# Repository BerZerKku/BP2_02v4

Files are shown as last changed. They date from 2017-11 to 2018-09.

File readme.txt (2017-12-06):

BP2
Блок питания задний для аппаратуры АВАНТ.

Версия платы: 02v7.
Дата создания: декабрь 2017.
Среда разработки: OrCAD 16.6-S073.
База: greysql.

Код ПП: 3.140.626
Код ПП в сборе: 2.140.896

Изменения:
Добавлен PFC и входной фильтр (за основу взяты платы AVAX_PWR_PFCS6_V100 и AVAX_PWR_PFCS6_V110). 
Источники AC-DC оставлены только TMG.
Изменены держатели для предохранителей.
Изменена схема компаратора в управлении 24В -> 5В.

Пороги для управления 5В рассчетные / реальные:
***Включение - 22 В / ?? В.
***Выключение - 20 В / ?? В. 

Пороги для управления 220В рассчетные / реальные:
***Включение - ?? В / ?? В.
***Выключение -?? В / ?? В.

Стэк:
0.035 TOP
1.500  
0.035 BOTTOM

Габариты платы: 233мм х 103мм
Материал: FR4 (e=4.1, plating thickness=25um))
Финишное покрытие контактных площадок: HAL
Паяльная маска: зеленая.
Маркировка: только со стороны TOP.
Вырезы на плате: есть.
Отверстия указаны после металлизации.

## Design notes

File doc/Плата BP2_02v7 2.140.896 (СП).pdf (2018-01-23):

Напечатано: 19 января 2018 г. 14:16:34, Щеблыкин Михаил Владимирович
Поз. | Наименование | Корпус | Кол. | Поз. по Э3 | Примечание
| Документация
| Сборочный чертеж 2.140.896 | | 0
| Сборочные единицы
1 | [3.181.006] Радиатор для AVAX.PWR.PFCS6 | LEAD-2 | 1 | B1
| Детали
2 | [3.140.626] Печатная плата BP2_02v7 2L/200um/0.4mm | | 1
| Прочее
| Источники питания
3 | [TMG 15105] Преобразователь напряжения TMG 15105 TRACO | DIP4 | 1 | UG1
4 | [TMG 15124] Преобразователь напряжения TMG 15124 TRACO | DIP4 | 1 | UG2
| Конденсаторы
7 | [B41858C6477M] Конденсатор B41858C6477M 470uF 50V 20% Epcos | LEAD | 2 | C1, C6
8 | [1210-X5R-50V-10uF -10%] Чип-конденсатор 1210 X5R 50V 10uF 10% | 1210 | 2 | C2, C7
9 | [DE1B3KX471KA5B] Конденсатор DE1B3KX471KA5B 470pF 250V 10% X1/Y1 Murata | LEAD | 2 | C3, C4 | Допустимые замены: [DE1B3KX471KA4 BN01F] Конденсатор DE1B3KX471KA4B N01F Murata

2.140.896

| Лист | № докум | Подп. | Дата
Разраб. | Щеблыкин М.В. | | 01.12.2017 | Плата BP2_02v7 (Плата BP2_02v7) | Лит. | Лист | Листов
Провер. | Вершинин А.С. | | 01.12.2017 | | | 1 | 9
Т.контр. | Бокова Т.И. | | 01.12.2017 | | Прософт-Системы
Н.контр. | Назаренко А.Н. | | 01.12.2017
Утв. | Чирков А.Г. | | 01.12.2017

10 | [B43501B9107M] Конденсатор B43501B9107M Epcos | LEAD | 1 | C5
11 | [B32922C3474M] Конденсатор B32922C3474M 305V | LEAD | 3 | C10, C11, C20
| 0.47uF 20% Epcos
12 | [DECE33J222ZC4B] Конденсатор DECE33J222ZC4B 2200pF 6.3kV Murata | LEAD | 4 | C12-C15
13 | [2220-X7R-1000V-0. 1uF-10%] Чип-конденсатор 2220 X7R 1000V 0.1uF 10% | 2220 | 2 | C16, C23
14 | [UBT1E101MPD1TD] Конденсатор UBT1E101MPD1TD 25V 100uF 20% 8*13.5mm Nichicon | LEAD | 1 | C17
15 | [0603-X7R-50V-0.1u F-10%] [+] Чип-конденсатор 0603 X7R 50V 0.1uF 10% | 0603 | 4 | C18, C29, C31, C33
16 | [1210-X7R-25V-10uF -10%] [+] Чип-конденсатор 1210 X7R 25V 10uF 10% | 1210 | 1 | C19
17 | [EEU-ED2G470S] Конденсатор EEU-ED2G470S 47UF 400V 20% Panasonic | LEAD | 2 | C21, C22
18 | [0603-NP0-50V-820p F-5%] Чип-конденсатор 0603 NP0 50V 820pF 5% | 0603 | 1 | C24

2.140.896

Лист

2 Изм | Лист | № докум | Подп. | Дата

19 | [0603-X7R-50V-1500 pF-10%] Чип-конденсатор 0603 X7R 50V 1500pF 10% | 0603 | 1 | C25
20 | [0603-X5R-10V-10uF -10%] Чип-конденсатор 0603 X5R 10V 10uF 10% | 0603 | 2 | C26, C32
21 | [0603-X7R-50V-0.15 uF-10%] Чип-конденсатор 0603 X7R 50V 0.15uF 10% | 0603 | 1 | C27
22 | [0603-NP0-50V-680p F-5%] Чип-конденсатор 0603 NP0 50V 680pF 5% | 0603 | 1 | C28
23 | [0603-X7R-50V-1uF-10%] Чип-конденсатор 0603 X7R 50V 1uF 10% | 0603 | 1 | C30
24 | [0603-X7R-50V-0.01 uF-10%] [+] Чип-конденсатор 0603 X7R 50V 0.01uF 10% | 0603 | 2 | C34, C35
| Предохранители,держатели предохранителей
30 | [ZH214-040] Предохранитель 4А 5*20мм Zhenhui Electronics | | 2 | F1, F2
| Дроссели, фильтры, катушки индуктивности
34 | [SDR2207-4R7ML] Индуктивность SDR2207-4R7ML Bourns | SMT-2 | 2 | L1, L2
35 | [744834407] Дроссель 744834407 Wurth | LEAD-4 | 2 | L3, L4
| | | | 3 Изм
Лист | № докум | Подп. | Дата

36 | [CDRH127/LDNP-471M C] Индуктивность CDRH127/LDNP-471MC | SMD | 1 | L5
| Sumida
37 | [2.210.500] Дроссель AVAX.PWR.PFCINDUCT OR-v1.0.0 (AVAX.PWR.PFCINDUC TOR-v1.0.0 СП) | SMD | 1 | L6
| Резисторы
41 | [1210-33K-5%] Чип-резистор 1210 33K 5% | 1210 | 4 | R1, R3-R5
42 | [1206-1K-5%] Чип-резистор 1206 1K 5% | 1206 | 1 | R2
43 | [1206-4.7K-5%] Чип-резистор 1206 4.7K 5% | 1206 | 1 | R6
44 | [1206-1-1%] Чип-резистор 1206 1 1% | 1206 | 1 | R7
45 | [1206-200K-5%] Чип-резистор 1206 200K 5% | 1206 | 3 | R8, R10, R11
46 | [0603-10K-5%] Чип-резистор 0603 10K 5% | 0603 | 7 | R9, R16, R24, R31, R32, R34, R36
47 | [1206-150K-1%] Чип-резистор 1206 150K 1% | 1206 | 1 | R12
48 | [0805-51K-1%] Чип-резистор 0805 51K 1% | 0805 | 1 | R13
49 | [2512-0.051-5%] Чип-резистор 2512 0.051 5% | 2512 | 1 | R14
50 | [1206-510K-1%] Чип-резистор 1206 510K 1% | 1206 | 2 | R15, R19
| | | | 4 Изм
Лист | № докум | Подп. | Дата

51 | [0603-3.3-5%] Чип-резистор 0603 3.3 5% | 0603 | 1 | R17
52 | [0603-220-5%] Чип-резистор 0603 220 5% | 0603 | 1 | R18
53 | [0603-51K-1%] Чип-резистор 0603 51K 1% | 0603 | 1 | R20
54 | [0603-18K-1%] Чип-резистор 0603 18K 1% | 0603 | 1 | R21
55 | [0603-14.7K-1%] Чип-резистор 0603 14.7K 1% | 0603 | 1 | R22
56 | [0603-2K-1%] Чип-резистор 0603 2K 1% | 0603 | 1 | R23
57 | [0603-1M-1%] Чип-резистор 0603 1M 1% | 0603 | 1 | R25
58 | [0603-4.7K-5%] Чип-резистор 0603 4.7K 5% | 0603 | 1 | R26
59 | [0805-100K-1%] [+] Чип-резистор 0805 100K 1% | 0805 | 3 | R27-R29
60 | [0603-10K-1%] Чип-резистор 0603 10K 1% | 0603 | 1 | R30
61 | [0603-2.2K-5%] Чип-резистор 0603 2.2K 5% | 0603 | 2 | R33, R37
62 | [0603-10.5K-1%] Чип-резистор 0603 10.5K 1% | 0603 | 1 | R35
63 | [0603-8.25K-1%] Чип-резистор 0603 8.25K 1% | 0603 | 1 | R38
64 | [0603-255K-1%] Чип-резистор 0603 255K 1% | 0603 | 1 | R39
| | | | 5 Изм
Лист | № докум | Подп. | Дата

65 | [0603-2.4K-1%] Чип-резистор 0603 2.4K 1% | 0603 | 1 | R40
66 | [JVR-14N391K] Варистор JVR-14N391K | LEAD-2 | 1 | RV1
67 | [JNR15S470L] Термистор JNR15S470L | LEAD-2 | 1 | TH1
68 | [JNR15S070L] Резистор JNR15S070L терморезистор Joyin | LEAD-2 | 1 | TH2
| Микросхемы
74 | [UCC28722DBV] Микросхема UCC28722DBV SOT23-6 TI | SOT23-6 | 1 | U1
75 | [UCC28180D] Микросхема UCC28180D SOIC8 TI | SOIC8 | 1 | U2
76 | [TL431AIDBZ] Микросхема TL431AIDBZ SOT23-3 TI | SOT23-3 | 2 | U3, U5
77 | [ACPL-M50L-500E] Микросхема ACPL-M50L-500E SO5 Avago | SO5 | 1 | U4
| Диоды,светодиоды,супрессоры,стабилитроны
81 | [S3M] Диод S3M SMC | SMC(DO -214 | 1 | D1
82 | [GBU8J-BP] Диодный мост GBU8J-BP MCC | SIP4 | 1 | D2
83 | [SM4007] Диод SM4007 DO-213AB | DO-213 AB | 1 | D3
84 | [US1M] Диод US1M /1A, 1000V, 100ns SMA/DO-214AC | SMA(DO -214 | 1 | D4
| | | | 6 Изм
Лист | № докум | Подп. | Дата

85 | [ES1J] Диод ES1J SMA | DO-214 AC | 1 | D5
86 | [BZX84C24] Стабилитрон BZX84C24 SOT23 | SOT23-3 | 1 | D6
87 | [1N5408] Диод 1N5408 DO-201AD | DO-201 AD | 1 | D7
88 | [C3D06060F] Диод C3D06060F Cree | TO220-2 | 1 | D8
89 | [MBR0540] Диод MBR0540 SOD123 | SOD123 | 1 | D9
90 | [KP-1608SGC] Светодиод KP-1608SGC Kingbright (level:3) | 0603 | 1 | D10
| Транзисторы
94 | [FJP2145TU] Транзистор FJP2145TU TO-220AB ONS | TO-220 AB | 1 | Q1
95 | [IPP60R099C7XKSA1] Транзистор IPP60R099C7XKSA1 TO-220 Infineon | TO220 | 1 | Q2
96 | [IRLML5103] Транзистор IRLML5103 SOT23 IR | SOT23-3 | 2 | Q3, Q5
97 | [IRF7410] Транзистор IRF7410 SOIC8 IR | SOIC8 | 1 | Q4
| Соединители
101 | [MC000830] Держатель предохранителя MC000830 MULTICOMP | LEAD-2 | 2 | FU1, FU2
102 | [09061152911] Соединитель DIN41612-H15MS-C2A -1 | 15 | 1 | X1
| | | | 7 Изм
Лист | № докум | Подп. | Дата

103 | [231-536/001-000] | 6 | 1 | X2
| Вилка 1X1 шаг
| 5,08 мм (100 шт)
| | | | 8 Изм
Лист | № докум | Подп. | Дата

Лист регистрации ревизий

№ ревизии | № замененных (измененных) страниц | Дата ревизии | Краткое содержание и причина внесения изменений | Примечание
0 | вновь | 01.12.17

2.140.896

9

Лист Изм. | Лист | № докум. | Подп. | Дата

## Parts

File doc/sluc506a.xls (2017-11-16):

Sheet: DESIGN INPUTS AND CALCULATIONS
UCC28180 DESIGN CALCULATOR TOOL
TI Literature Number: | SLUC506 | Rev A
UCC28180 CONTINUOUS CURRENT CONDUCTION MODE PFC CONTROLLER WITH PROGRAMMABLE SWITCHING FREQUENCY
Please enter design parameters into the | shaded | cells;
Calculated results will be in RED
Be sure to ENABLE EDITING before attempting to use this design calculator
This spreadsheet guides the user through the design process of a CONTINUOUS CONDUCTION MODE PFC BOOST CONVERTER using the UCC28180. User interaction is required in order to get the best possible results. Enter the desired specification where prompted, the highlighted cells are for user inputs; calculations for the design are based upon the inputs.
WHERE APPLICABLE, A RECOMMENDED VALUE IS GIVEN THAT WILL BE THE BEST CHOICE TO MEET THE GIVEN SPECIFICATION. IT IS IN THE BEST INTEREST OF THE USER TO USE A VALUE AS CLOSE AS POSSIBLE TO THE SUGGESTED RECOMMENDED VALUE. FOR ACCURATE RESULTS, THE USER MUST ENTER THE ACTUAL VALUE USED IN THE APPROPRIATE CELL.
Disclaimer
This product is designed as an aid for customers of Texas Instruments. No warranties, either expressed or implied, with respect to this software or its fitness for any particular purpose, are claimed by Texas Instruments or the author. The software is licensed solely on an "as is" basis. The entire risk as to its quality and performance is with the customer.
INPUT:
Minimum Input Voltage from AC Line: | VACIN(min) | 82 | VRMS
Maximum Input Voltage from AC Line: | VACIN(max) | 242 | VRMS
Minimum Line Frequency: | fLINE(min): | 47 | Hz
Maximum Line Frequency: | fLINE(max): | 63 | Hz
Minimum Rectified AC Line Voltage: | VIN_PEAK(min) | 115.966 | V
Maximum Rectified AC Line Voltage: | VIN_PEAK(max) | 342.240 | V
OUTPUT:
Maximum Output Power of PFC Stage: | POUT(max) | 190 | W
Output Voltage (Note: Must be > VIN_RECTIFIED(max)): | VOUT | 350 | V
Target Power Factor, VIN(nom), Full Load: | PF | 0.99
Predicted Efficiency: | h | 0.95
Maximum Ambient Temperature: | TAMB(max) | 50 | °C
Maximum Average Output Current of PFC Stage: | IOUT | 0.543 | A
Desired Switching Frequency: | fSW(target) | 120 | kHz
Recommended Resistor value on FREQ to Set the Switching Frequency, fSW: | RFREQ(recommended) | 17.800 | kΩ
Actual Value For RFREQ Used: | RFREQ = | 18 | kΩ
Resultant Switching Frequency, fSW: | fSW | 116.402 | kHz
Line Current:
Maximum Input Power Drawn from the Line: | PIN(max) | 200.000 | W
Maximum RMS AC Line Current: | IIN_RMS(max) | 2.464 | A
Maximum Peak AC Line Current, assuming sinusoidal: | IIN_PEAK(max) | 3.484 | A
Maximum Average AC Line Current, assuming sinusoidal: | IIN_AVG(max) | 2.218 | A
Minimum Input Fuse Rating: | IFUSE | 3.695 | A
BRIDGE RECTIFIER:
Bridge Rectifier Forward Voltage, at IIN_PEAK(max): | VF_BRIDGE | 1 | V
Bridge Rectifier Thermal Resistance, Junction to Case: | RqJC(Bridge) | 2.2 | °C/W
Case to Heatsink Thermal Resistance: | RθCHS(Bridge) | 0.61 | °C/W
Bridge Rectifier Maximum Junction Temperature: | TJ(max) | 125 | °C
Bridge Rectifier Minimum Average Current Rating: | IBRIDGE(rated) | 3.327 | A
Bridge Rectifier Minimum DC Blocking Voltage Rating: | VDC_BLOCKING(rated) | 376.464 | V
Bridge Rectifier Power Dissipation: | PBRIDGE | 4.436 | W
Required Heat Sink Thermal Impedance: | RqHS_AMB(Bridge) | 14.097 | °C/W
INPUT CAPACITOR:
Inductor Peak-to-Peak Current Ripple Factor (i.e. 0.2 for 20%, 0.3 for 30%). Percentage of minimum input, maximum load, inductor current at 50% duty cycle operating point, not recommended to be > 0.4: | LI_ripple_factor(target) | 0.4
Maximum High Frequency Voltage Ripple Factor (i.e. 0.03 for 3%, 0.09 for 9%): | VCin_ripple_factor | 0.07
Target Maximum Allowable Inductor Current Ripple: | IRIPPLE(target) | 1.394 | A
Maximum Inductor Voltage Ripple: | VIN_RIPPLE | 8.118 | V
Recommended Input Capacitor Value: | CIN(recommended) | 0.180 | mF
Actual Value of Input Capacitor Used: | CIN | 0.470 | µF
Required Minimum Voltage Rating for CIN: | VCIN(rating) | 376.464 | V
BOOST INDUCTOR DESIGN:
Maximum Duty Cycle: | DUTY(max) | 0.669
Maximum Inductor Peak Current: | IL_PEAK(max) | 4.181 | A
Minimum Recommended Boost Inductor Value: | LBST(recommended) | 0.539 | mH
Actual Boost Inductor Value Used: | LBST(actual) = | 0.6 | mH
Actual Maximum Inductor Ripple Current: | IRIPPLE(actual) | 1.253 | A
Actual Maximum Inductor Peak Current: | IL_PEAK(actual) | 4.111 | A
Resultant Inductor Current Ripple Factor: | LI_ripple_factor(actual) | 0.360
BOOST DIODE:
Forward Voltage Drop, at IL_PEAK(max),125°C: | VF | 1 | V
Reverse Recovery Charge: | QRR | 0 | nC
Boost Diode Maximum Junction Temperature: | TJ(max) | 125 | °C
Boost Diode Thermal Resistance, Junction to Case: | RqJC(Diode) | 1.5 | °C/W
Boost Diode Thermal Resistance, Case to Heatsink: | RqCHS(Diode) | 0.32 | °C/W
Boost Diode Conduction Losses: | PDIODE(cond) | 0.543 | W
Reverse Recovery Losses: | PREVERSE | 0.000 | W
Total Boost Diode Losses: | PDIODE(total) | 0.543 | W
Required Heat Sink Thermal Impedance: | RqHS_AMB(Diode) | 136.338 | °C/W
Required Diode Blocking Voltage: | VBLOCKING | 385.000 | V
SWITCHING ELEMENT:
VCC Bias Voltage to the UCC28180: | VCC | 15 | V
Gate-Source Voltage: | VGS | 13.75 | V
Drain-Source RMS Current: | IDS_RMS | 1.964 | A
FET On-Resistance at TJ = 125°C: | RDSon | 0.35 | W
FET Gate Charge at VGS: | Qg | 87 | nC
FET Rise Time: | tr | 5 | ns
FET Fall Time: | tf | 4.5 | ns
FET Output Capacitance: | COSS | 780 | pF
FET Maximum Junction Temperature: | TJ(max) | 125 | °C
FET Thermal Resistance, Junction to Case: | RqJC(FET) | 0.61 | °C/W
FET Thermal Resistance, Case to Heatsink: | RqCHS(FET) | 0.32 | °C/W
Gate Drive Losses (actually dissipated in the gate drive circuitry): | PGATE | 0.139 | W
FET Conduction Losses: | PCOND | 1.351 | W
FET Switching Losses: | PSW | 6.235 | W
FET Losses, Total: | PFET | 7.586 | W
Required Heat Sink Thermal Impedance: | RqHS_AMB(FET) | 8.957 | °C/W
CURRENT SENSE RESISTOR:
Ideal Value for RSENSE, for 110% Inductor SOC Threshold: | RSENSE(ideal) | 0.057 | W
Actual Value for RSENSE: Current Sense Resistor: | RSENSE | 0.051 | W
Inductor Current at Soft Over-Current Threshold: | IOVERCURRENT_SOC | 5.078 | A
Power Dissipated in RSENSE: | PRsense | 0.310 | W
Theoretical Output Over-Current Inception Point: | IOUT_OVERCURRENT | 0.705 | A
Maximum ISENSE Peak Current Limit Threshold: | IPCL | 8.588 | A
Resistance of Thermistor at 25°C: | RTHERM | 7 | W
Maximum Inrush Current: | IINRUSH | 48.891 | A
Recommended ISENSE Series Resistor: | RISENSE | 220 | W
Recommended ISENSE Filter Capacitor: | CISENSE | 820 | pF
OUTPUT CAPACITOR:
Required Minimum Output Voltage: | VOUT_HOLDUP(min) | 300 | V
Desired Number of Line Cycles For Output Holdup Time (typ one line cycle): | NHOLD_UP | 1
Minimum Output Voltage Holdup Time: | tHold_UP(min) | 21.277 | ms
Recommended Minimum Output Capacitor Value: | COUT(recommended) | 270.000 | µF
Actual Output Capacitor Value: | COUT | 470 | µF
Output Voltage Peak to Peak Ripple: | VOUT_RIPPLEpp | 1.956 | V
Good! Output voltage peak-peak ripple is less than 5% VOUT
Output Capacitor Ripple Current at Twice Line Frequency: | ICout_2fline | 0.384 | ARMS
Output Capacitor High Frequency Ripple Current: | ICout_HF | 1.033 | ARMS
Total Output Capacitor Ripple Current: | ICout_RMS(total) | 1.102 | ARMS
OUTPUT VOLTAGE SET POINT:
Recommended Value for the Top Divider Resistor: | RFB1(recommended) | 1 | MW
Actual Value of the Top Divider Resistor: | RFB1(actual) | 1.02 | MW
Recommended Value for the Bottom Divider Resistor (E48 Series): | RFB2(recommended) | 14.700 | kW
Actual Value of the Bottom Divider Resistor: | RFB2(actual) | 14.7 | kW
Actual Nominal Output Voltage: | VOUT | 351.939 | V
Minimum Output Voltage with respect to VREF: | VOUT(min) | 347.012 | V
Maximum Output Voltage with respect to VREF: | VOUT(max) | 356.866 | V
OVP Set Point: Typical DC Output Voltage to Trigger OVP: | VOVP | 383.613 | V
UVD Set Point: Typical DC Output Voltage to Trigger UVD: | VUVD | 334.342 | V
Recommended Value for Filter Capacitor on VSENSE: | CVSENSE | 680.000 | pF
Power Dissipated in Voltage Divider: | PRfB1+RFB2 | 0.120 | W
COMPENSATION:
The Loop will be Optimized at a Selected Specific Line Voltage. For a Wide Input Range, Optimization is Recommended at the Mean of Min and Max Input. For a Design with a Specific Nominal Line Voltage, Optimize at that Nominal Voltage. VCOMP at Any Line Voltage or as a Function of Load is Shown at Right |  |  |  | To Determine VCOMP for a Specific Line Voltage at Full Load:
Line Voltage for Optimized Loop Design: | VINnom | 220 | V |  | Enter Line Voltage for VCOMP calculation | VLINE | 115.000 | VRMS
Open Loop Transfer Function for Current Loop: |  |  |  |  | Resultant VCOMP at Full Load | VCOMP at VLINE | 2.806 | V
Product of the Voltage Loop Variables: | M1M2 | 0.152 | V/ms
VCOMP Voltage at VINnom: | VCOMP | 2.123 | V | To Determine VCOMP at Selected Line Voltage and at a Specific Load, enter a value from 1 to 100 for 1% to 100% load:
Internal Current Loop Gain Factor M1: | M1 | 0.263
Internal Voltage Loop PWM Ramp Slope M2: | M2 | 0.577 | V/ms |  | Percentage of Full Load for VCOMP Calculation: | % of Full Load: | 50 | %
Non-Linear Gain Voltage Loop Variable M3: | M3 | 0.368 | V/ms |  | Resultant VCOMP at Selected Load | VCOMP at %load selected | 2.402 | V
Maximum Recommended ICOMP Capacitor Value: | CICOMPmax(recommended) | 1800.000 | pF
Minimum Recommended ICOMP Capacitor Value: | CICOMPmin(recommended) | 1000.000 | pF
Actual Value Used for ICOMP Capacitor: | CICOMP(actual) | 1500 | pF
Resultant Actual Current Averaging Pole Frequency: | fIAVG(actual) | 3.793 | kHz
Open Loop Transfer Function for Voltage Loop:
PWM to Power Stage Pole: | fPWM_PS(pole) | 0.298 | Hz
Desired Voltage Loop Crossover Frequency ( fV < 20Hz): | fV | 10 | Hz
Open Loop Voltage Gain at Desired fV: | GVLdB(fV) | -8.858 | dB
Recommended Value for the Voltage Compensation Capacitor: | CVCOMP(recommended) | 10.000 | µF
Actual Value Used for CVCOMP Capacitor: | CVCOMP(actual) | 10 | mF
Recommended Value for the Voltage Compensation Resistor: | RVCOMP(recommended) | 53.600 | kW
Actual Value Used for RVCOMP Resistor: | RVCOMP(actual) | 51 | kW
Resultant Value of Voltage Compensation Zero: | fZERO | 0.312 | Hz
Desired Voltage Compensation Pole (fPole < 50Hz): | fPOLE | 20 | Hz
Recommended Value for the Parallel Voltage Compensation Capacitor: | CVCOMP_P(recommended) | 0.150 | µF
Actual Value for the Parallel Voltage Compensation Capacitor: | CVCOMP_P(actual) | 0.15 | mF

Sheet: SCHEMATIC
Typical Schematic for a PFC Continuous Conduction Mode Boost Converter Using the UCC28180
 | RECOMMENDED BILL OF MATERIALS
 | Reference Designator | Description/Comments
 | FUSE | Type: | Fast Acting
 |  | Voltage Rating: | 250 | VRMS
 |  | Current Rating: | 3.70 | A
 | BRIDGE | DC Blocking Voltage: | 376.4636503 | V
 |  | Current Rating: | 3.33 | A
 |  | Power Dissipation: | 4.44 | W
 | CIN | Type: | Film Capacitor, X2
 |  | Value: | 0.47 | µF
 |  | Volatge Rating: | 242 | VRMS
 | LBST | Inductor Value: | 0.60 | mH
 |  | Peak Current Rating: | 4.11 | A
 |  | Ripple Current: | 1.25 | A
 |  | Maximum Duty Cycle: | 0.669
 | DBOOST | Type: | Diode, Low Reverse Recovery Charge, Schottky
 |  | Average Current Rating: | 2.22 | A
 |  | Volatge Rating: | 385 | V
 |  | Power Dissipation: | 0.54 | W
 | QFET | Type: | MOSFET, Nchannel
 |  | RMS Drain Current Rating: | 1.96 | A
 |  | Peak Current Rating: | 4.11 | A
 |  | Voltage Rating: | 342.2396821 | V
 |  | Power Dissipation: | 7.59 | W
 | RSENSE | Type: | Resistor, Low Inductance
 |  | Value: | 0.051 | W
 |  | Power Dissipation: | 0.31 | W
 | RISENSE | Type: | Resistor, Chip, 1/16W
 |  | Value: | 220 | W
 | CISENSE | Type: | Capacitor, Ceramic, 100V, X7R, ±10%
 |  | Value: | 820 | pF
 | COUT | Type: | Capacitor, Aluminum, ±20%
 |  | Value: | 470 | µF
 |  | Voltage Rating: | 383.613 | V
 |  | 2 x fLINE Ripple Current Rating: | 0.384 | ARMS
 |  | HF Ripple Current Rating: | 1.033 | ARMS
 | RFB1 | Type: | Resistor, Chip, Total Voltage Rating 400V, ±1%
 |  | Value: | 1.02 | MW
 | RFB2 | Type: | Resistor, Chip, 1/10W, ±1%
 |  | Value: | 14.7 | kW
 | CVSENSE | Type: | Capacitor, Ceramic, 50V, X7R, ±10%
 |  | Value: | 680 | pF
 | CICOMP | Type: | Capacitor, Ceramic, 50V, X7R, ±10%
 |  | Recommended Values: | 1000 | pF min
 |  |  | 1800 | pF min
 | CVCOMP | Type: | Capacitor, Ceramic, 10V, X5R, ±10%
 |  | Value: | 10 | mF
 | RVCOMP | Type: | Resistor, Chip, 1/10W, ±1%
 |  | Value: | 51 | kW
 | CVCOMP_P | Type: | Capacitor, Ceramic, 10V, X5R, ±10%
 |  | Value: | 0.15 | mF
 | RFREQ | Type: | Resistor, Chip, 1/10W, ±1%
 |  | Value: | 18 | kΩ
 | CVCC | Type: | Ceramic, Low ESR/ESL, placed close to the VCC and GND pins with short traces
 |  | Values: | 0.1 | mF min
 |  |  | 1 | mF max
 | DSTART | Type: | Diode, Switching
 |  | Average Current Rating: | 48.891 | A
 |  | Volatge Rating: | 383.613 | V
 | DTURNOFF | Type: | Diode, Schottky
 |  | Average Current Rating: | 2 | A
 |  | Volatge Rating: | 40.000 | V
 | RGATE | Type: | Resistor, Chip, 1/10W, ±1%
 |  | Value: | As Needed
 | RGATE2 | Type: | Resistor, Chip, 1/10W, ±1%
 |  | Value: | 10 | kΩ

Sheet: data
Data for M1M2 vs VCOMP table
VCOMP | M1 | M2 | M1M2
0 | 0.068 | 0.000 | 0.000 |  |  | mV factor | 0.001
0.05 | 0.068 | 0.000 | 0.000 |  |  | uF factor | 1e-06
0.1 | 0.068 | 0.000 | 0.000 |  |  | kHz factor | 1000
0.15 | 0.068 | 0.000 | 0.000 |  |  | mΩ factor | 0.001
0.2 | 0.068 | 0.000 | 0.000 |  |  | ms factor | 0.001
0.25 | 0.068 | 0.000 | 0.000 |  |  | mA factor | 0.001
0.3 | 0.068 | 0.000 | 0.000 |  |  | us factor | 1e-06
0.35 | 0.068 | 0.000 | 0.000 |  |  | uH factor | 1e-06
0.4 | 0.068 | 0.000 | 0.000 |  |  | ns factor | 1e-09
0.45 | 0.068 | 0.000 | 0.000 |  |  | mW factor | 0.001
0.5 | 0.068 | 0.000 | 0.000 |  |  | pF factor | 1e-12
0.55 | 0.068 | 0.001 | 3.838338462e-05 |  |  | MHz factor | 1000000
0.6 | 0.068 | 0.002 | 0.0001535335385 |  |  | uA factor | 1e-06
0.65 | 0.068 | 0.005 | 0.0003454504615 |  |  | kΩ factor | 1000
0.7 | 0.068 | 0.009 | 0.001 |  |  | nC factor | 1e-09
0.75 | 0.068 | 0.014 | 0.001 |  |  | nF factor | 1e-09
0.8 | 0.068 | 0.020 | 0.001 |  |  | uC factor | 1e-06
0.85 | 0.068 | 0.028 | 0.002 |  |  | MΩ factor | 1000000
0.9 | 0.068 | 0.036 | 0.002 |  |  | mH factor | 0.001
0.95 | 0.068 | 0.046 | 0.003
1 | 0.068 | 0.056 | 0.004
1.05 | 0.076 | 0.068 | 0.005
1.1 | 0.084 | 0.081 | 0.007
1.15 | 0.091 | 0.095 | 0.009
1.2 | 0.099 | 0.111 | 0.011
1.25 | 0.107 | 0.127 | 0.014
1.3 | 0.115 | 0.145 | 0.017 |  |  | K1 | 7
1.35 | 0.123 | 0.163 | 0.020 |  |  | KFQ | 8.590882811e-06
1.4 | 0.130 | 0.183 | 0.024 |  |  | fTYP | 65000 |  | VINnom | 162
1.45 | 0.138 | 0.204 | 0.028
1.5 | 0.146 | 0.226 | 0.033 |  |  | M1M2 | 0.1519222056 |  | M1M2 | 0.2801796507
1.55 | 0.154 | 0.249 | 0.038
1.6 | 0.162 | 0.273 | 0.044 |  |  | VCOMP1 | 3.693879426 |  | VCOMP1 | 3.693879426
1.65 | 0.169 | 0.299 | 0.051
1.7 | 0.177 | 0.325 | 0.058 |  |  | a1 | 0.156 |  | a1 | 0.156
1.75 | 0.185 | 0.353 | 0.065 |  |  | b1 | 0.088 |  | b1 | 0.088
1.8 | 0.193 | 0.382 | 0.074 |  |  | c1 | 0.1223 |  | c1 | 0.1223
1.85 | 0.201 | 0.411 | 0.083 |  |  | d1 | 0.5 |  | d1 | 0.5
1.9 | 0.208 | 0.443 | 0.092 |  |  | K1V2 | 2.225327694 |  | K1V2 | 2.225327694
1.95 | 0.216 | 0.475 | 0.103 |  |  | K2V2 | 2.221256734 |  | K2V2 | 2.221256734
2 | 0.225 | 0.508 | 0.114 |  |  | K3V2 | 0.0004565709694 |  | K3V2 | 0.0004565709694
2.05 | 0.241 | 0.542 | 0.131 |  |  | K4V2 | 0.5213675214 |  | K4V2 | 0.5213675214
2.1 | 0.256 | 0.578 | 0.148 |  |  | VCOMP2 | 2.166122456 |  | VCOMP2 | 2.166122456
2.15 | 0.272 | 0.615 | 0.167
2.2 | 0.288 | 0.653 | 0.188 |  |  | a2 | 0.313 |  | a2 | 0.313
2.25 | 0.303 | 0.691 | 0.210 |  |  | b2 | 0.401 |  | b2 | 0.401
2.3 | 0.319 | 0.732 | 0.233 |  |  | c2 | 0.1223 |  | c2 | 0.1223
2.35 | 0.335 | 0.773 | 0.259 |  |  | d2 | 0.5 |  | d2 | 0.5
2.4 | 0.350 | 0.815 | 0.285 |  |  | K1V3 | 0.07325223506 |  | K1V3 | 0.07325223506
2.45 | 0.366 | 0.859 | 0.314 |  |  | K2V3 | 1.26696796 |  | K2V3 | 1.26696796
2.5 | 0.381 | 0.903 | 0.345 |  |  | K3V3 | 1.052482911 |  | K3V3 | 1.052482911
2.55 | 0.397 | 0.949 | 0.377 |  |  | K4V3 | 0.06779950801 |  | K4V3 | 0.06779950801
2.6 | 0.413 | 0.996 | 0.411 |  |  | K5V3 | 0.7603833866 |  | K5V3 | 0.7603833866
2.65 | 0.428 | 1.044 | 0.447 |  |  | VCOMP3 | 2.122743088 |  | VCOMP3 | 2.122743088
2.7 | 0.444 | 1.093 | 0.485
2.75 | 0.460 | 1.143 | 0.526 |  |  | a3 | 1.007 |  | a3 | 1.007
2.8 | 0.475 | 1.194 | 0.568 |  |  | b3 | 0.1223 |  | b3 | 0.1223
2.85 | 0.491 | 1.247 | 0.612 |  |  | c3 | 0.5 |  | c3 | 0.5
2.9 | 0.507 | 1.301 | 0.659 |  |  | VCOMP4 | 1.329962061 |  | VCOMP4 | 1.329962061
2.95 | 0.522 | 1.355 | 0.708
3 | 0.538 | 1.411 | 0.759 |  |  | a4 | 1.007 |  | a4 | 1.007
3.05 | 0.554 | 1.468 | 0.813 |  |  | b4 | 2.056 |  | b4 | 2.056
3.1 | 0.569 | 1.526 | 0.869 |  |  | VCOMP5 | 3.707673043 |  | VCOMP5 | 3.707673043
3.15 | 0.585 | 1.586 | 0.927
3.2 | 0.601 | 1.646 | 0.989 |  |  | VCOMP = | 2.122743088 |  | VCOMP = | 2.122743088
3.25 | 0.616 | 1.707 | 1.052
3.3 | 0.632 | 1.770 | 1.119
3.35 | 0.648 | 1.834 | 1.188
3.4 | 0.663 | 1.899 | 1.259
3.45 | 0.679 | 1.965 | 1.334
3.5 | 0.694 | 2.032 | 1.411
3.55 | 0.710 | 2.100 | 1.492
3.6 | 0.726 | 2.170 | 1.575
3.65 | 0.741 | 2.240 | 1.661
3.7 | 0.757 | 2.312 | 1.750
3.75 | 0.773 | 2.385 | 1.843
3.8 | 0.788 | 2.459 | 1.939
3.85 | 0.804 | 2.534 | 2.037
3.9 | 0.820 | 2.610 | 2.139
3.95 | 0.835 | 2.687 | 2.245
4 | 0.851 | 2.766 | 2.354
4.05 | 0.867 | 2.845 | 2.466
4.1 | 0.882 | 2.926 | 2.582
4.15 | 0.898 | 3.008 | 2.701
4.2 | 0.914 | 3.091 | 2.824
4.25 | 0.929 | 3.175 | 2.950
4.3 | 0.945 | 3.260 | 3.081
4.35 | 0.961 | 3.347 | 3.215
4.4 | 0.976 | 3.434 | 3.352
4.45 | 0.992 | 3.523 | 3.494
4.5 | 1.007 | 3.613 | 3.640
4.55 | 1.007 | 3.703 | 3.729
4.6 | 1.007 | 3.795 | 3.822
4.65 | 1.007 | 3.796 | 3.822
4.7 | 1.007 | 3.796 | 3.822
4.75 | 1.007 | 3.796 | 3.822
4.8 | 1.007 | 3.796 | 3.822
4.85 | 1.007 | 3.796 | 3.822
4.9 | 1.007 | 3.796 | 3.822
4.95 | 1.007 | 3.796 | 3.822
5 | 1.007 | 3.796 | 3.822
Data For Current Averaging Bode Plot |  |  |  |  |  | Data For Open Loop Voltage Bode Plot |  |  |  |  |  |  |  |  | Data for Closed Loop Voltage Bode Plot
Log scale converter |  |  |  |  |  | Log scale converter |  |  |  |  |  |  |  | Total Open Loop Phase | EA Gain |  | Total Closed Voltage Loop Bode Plot
 | frequency | w | Gain |  | Phase |  | frequency | w | Voltage Feedback Gain | PWM to Power Stage Gain |  | Total Open Loop Gain |  |  |  | dB |  | dB | Phase Margin
 | Hz | rad |  | dB | degrees |  | Hz | rad | V/V |  | dB |  | dB | degrees |  |  |  |  |  | 1+sRVCOMPCVCOMP | s(CVCOMP+CVCOMP_P) | 1+S(rvcompcvcompcvcomp_p/CVCOMP+CVCOMPP)
1 | 10 | 62.83185307 | -16,8298909258867-6383,8423644083i | 76.10167327 | -90.15105002 | -2 | 0.010 | 0.063 | 0.014 | 850,982113484488-28,5442514257811i | 58.6032922 | 12,0899169500551-0,405528651743483i | 21.65334991 | -1.921135782 | 2,77220933244242-87,8109365830441i | 38.87529855 | -2,09407012345781-1062,75114090849i | 60.52864846 | 89.88710318 | 1+0,0320442450666159i | 6,37743308678728E-07i | 1+0,000473560271920432i
1.1 | 12.58925412 | 79.1006165 | -16,8298225108793-5070,84562255511i | 74.10165562 | -90.19016044 | -1.9 | 0.013 | 0.079 | 0.014 | 850,42310330919-35,9114777231658i | 58.60043838 | 12,0819750832561-0,51019495750511i | 21.65049609 | -2.418036852 | 2,77220896881807-69,7513161722647i | 36.87790284 | -2,09301010359506-844,148031054662i | 58.52839894 | 89.85793913
1.2 | 15.84893192 | 99.5817762 | -16,8297140815393-4027,88990130778i | 72.10162764 | -90.2393973 | -1.8 | 0.016 | 0.100 | 0.014 | 849,53863471724-45,162852095482i | 58.59591922 | 12,0694094233531-0,641629386105717i | 21.64597693 | -3.043072017 | 2,77220839251252-55,4062076968594i | 34.88202717 | -2,09133293489259-670,498935657779i | 56.52800411 | 89.82129105
1.3 | 19.95262315 | 125.3660286 | -16,8295422354783-3199,43400562399i | 70.10158329 | -90.30138232 | -1.7 | 0.020 | 0.125 | 0.014 | 848,140608798832-56,7630971662258i | 58.58876646 | 12,0495476460257-0,806434259537566i | 21.63882417 | -3.828897048 | 2,77220747913025-44,0116818205508i | 32.88855578 | -2,0886819355101-532,556460164167i | 54.52737995 | 89.77528759
1.4 | 25.11886432 | 157.8264792 | -16,8292698850145-2541,35963862033i | 68.10151301 | -90.37941582 | -1.6 | 0.025 | 0.158 | 0.014 | 845,934287705215-71,2746108023415i | 58.57745416 | 12,0182024057859-1,01259957359082i | 21.62751188 | -4.816109167 | 2,77220603151815-34,9609384895597i | 30.89888285 | -2,08449820953743-422,97476970918i | 52.52639473 | 89.71763804
1.5 | 31.6227766 | 198.6917653 | -16,8288382566746-2018,6219416538i | 66.10140162 | -90.47765213 | -1.5 | 0.032 | 0.199 | 0.014 | 842,460921103261-89,3609939600618i | 58.55958552 | 11,9688562290692-1,26955311801769i | 21.60964324 | -6.054802426 | 2,77220373721067-27,7719926167769i | 28.91520001 | -2,07791185183054-335,91844672333i | 50.52484324 | 89.64558642
1.6 | 39.81071706 | 250.1381125 | -16,8281542172069-1603,38322834345i | 64.10122509 | -90.60132026 | -1.4 | 0.040 | 0.250 | 0.014 | 837,014054414841-111,771473558542i | 58.53141538 | 11,891472504009-1,58793917204075i | 21.5814731 | -7.606049813 | 2,77220010098616-22,0620066177949i | 26.94093597 | -2,06758324573089-266,751830211864i | 48.52240906 | 89.55591149
1.7 | 50.11872336 | 314.9052262 | -16,827070201611-1273,53052732923i | 62.10094533 | -90.7570011 | -1.3 | 0.050 | 0.315 | 0.014 | 828,524162525928-139,284697277346i | 58.48713966 | 11,7708564696348-1,9788199961119i | 21.53719738 | -9.542866085 | 2,77219433797823-17,5269029124918i | 24.98141473 | -2,05148429487465-211,792332129265i | 46.51861211 | 89.44503319
1.8 | 63.09573445 | 396.4421916 | -16,8253524387164-1011,49798804411i | 60.10050196 | -90.95297548 | -1.2 | 0.063 | 0.396 | 0.014 | 815,415797380648-172,574787453394i | 58.41787909 | 11,58462570938-2,45177285741267i | 21.4679368 | -11.94975827 | 2,77218520427526-13,9251706830275i | 23.04480595 | -2,02662752687545-168,114658741668i | 44.51274275 | 89.30933102
1.9 | 79.43282347 | 499.0911493 | -16,8226306862727-803,331439368166i | 58.09979937 | -91.19966036 | -1.1 | 0.079 | 0.499 | 0.014 | 795,469294123125-211,944253701691i | 58.31032208 | 11,3012454079539-3,01109551504287i | 21.36037979 | -14.91925232 | 2,77217072845488-11,0650045380517i | 21.14341571 | -1,98880382344155-133,395602572029i | 42.50379551 | 89.14583673
2 | 100 | 628.3185307 | -16,8183188026383-637,94528760293i | 56.09868607 | -91.51015385 | -1 | 0.100 | 0.628 | 0.014 | 765,780539725117-256,863592271996i | 58.14513114 | 10,8794567835694-3,64926530047196i | 21.19518885 | -18.54285165 | 2,7721477861354-8,79409016807793i | 19.29525316 | -1,93250606266075-105,79122665814i | 40.49044201 | 88.95348479
2.1 | 125.8925412 | 791.006165 | -16,811489453534-506,532185048161i | 54.09692219 | -91.90091366 | -0.9 | 0.126 | 0.791 | 0.014 | 723,012963223959-305,312306560624i | 57.89554872 | 10,2718571174178-4,3375769850596i | 20.94560643 | -22.89325304 | 2,77211142578727-6,99149303689463i | 17.52552219 | -1,85140680879042-83,8398642329187i | 38.47112862 | 88.73496266
2.2 | 158.4893192 | 995.817762 | -16,8006770183774-402,094040157731i | 52.09412809 | -92.39259526 | -0.8 | 0.158 | 0.996 | 0.014 | 664,220383814186-353,110332209775i | 57.52720987 | 9,43658997010586-5,01664432539257i | 20.57726758 | -27.99583647 | 2,77205380047281-5,56121814422001i | 15.86715881 | -1,73991835533596-66,3853433291421i | 36.44442639 | 88.49865714
2.3 | 199.5262315 | 1253.660286 | -16,7835689239022-319,069410204552i | 50.08970342 | -93.01107591 | -0.7 | 0.200 | 1.254 | 0.014 | 588,390238304152-393,789094898051i | 57.00074247 | 8,35926983963568-5,59456817918368i | 20.05080018 | -33.79301712 | 2,77196247541153-4,42709787744909i | 14.35891671 | -1,59611859399883-52,5152388229039i | 34.40971689 | 88.25912026
2.4 | 251.1886432 | 1578.264792 | -16,7565256769927-253,037465855445i | 48.08270002 | -93.78868193 | -0.6 | 0.251 | 1.578 | 0.014 | 498,239753577579-419,794362737445i | 56.27847164 | 7,07850041325062-5,96402544915477i | 19.32852935 | -40.11597859 | 2,77181774726892-3,52873567999566i | 13.03950537 | -1,42515632933612-41,5093485542322i | 32.36803472 | 88.03361451
2.5 | 316.227766 | 1986.917653 | -16,7138430798546-200,482825111066i | 46.07162346 | -94.76561166 | -0.5 | 0.316 | 1.987 | 0.014 | 400,891267219618-425,230906399074i | 55.33435384 | 5,69546885873044-6,04126251480273i | 18.38441155 | -46.68758973 | 2,77158839957554-2,81828945805625i | 11.93804953 | -1,2405310398179-32,7953729480655i | 30.32246109 | 87.83373947
2.6 | 398.1071706 | 2501.381125 | -16,6466393416352-158,608852665306i | 44.05412596 | -95.99148815 | -0.4 | 0.398 | 2.501 | 0.014 | 306,102361907907-408,756721225139i | 54.16275469 | 4,34880131443533-5,80721349377553i | 17.2128124 | -53.17185606 | 2,77122498571138-2,25792330350215i | 11.06459674 | -1,06073581555023-25,9123549614753i | 28.27740914 | 87.65587605
2.7 | 501.1872336 | 3149.052262 | -16,5412285986109-125,189705203973i | 42.0265379 | -97.52685189 | -0.3 | 0.501 | 3.149 | 0.014 | 222,661882827461-374,320923245932i | 52.78054665 | 3,1633610491579-5,31798354278071i | 15.83060436 | -59.25403209 | 2,77064920872813-1,81779157501982i | 10.40636483 | -0,902421892390107-20,4845979587397i | 26.23696919 | 87.47754111
2.8 | 630.9573445 | 3964.421916 | -16,3768712079291-98,4536421309075i | 39.9831696 | -99.44416279 | -0.2 | 0.631 | 3.964 | 0.014 | 155,487294331139-329,073668392195i | 51.22103694 | 2,20901056022784-4,67515504529358i | 14.27109466 | -64.7092676 | 2,76973715363968-1,47444747963967i | 9.932350977 | -0,774891952012354-16,206020681001i | 24.20344563 | 87.26248348
2.9 | 794.3282347 | 4990.911493 | -16,122968990975-76,99204796178i | 37.91531045 | -101.8274444 | -0.1 | 0.794 | 4.991 | 0.014 | 105,190864261445-280,269765116504i | 49.52386811 | 1,49444834700226-3,98179718489669i | 12.57392583 | -69.42787939 | 2,76829287309206-1,20959040769272i | 9.603068461 | -0,679272972018346-12,8304511543737i | 22.17699429 | 86.96946173
3 | 1000 | 6283.185307 | -15,7363010074355-59,6902650603811i | 35.8098868 | -104.768998 | 0 | 1.000 | 6.283 | 0.014 | 69,5396267333543-233,254795615398i | 47.72641143 | 0,987950626249452-3,3138547362002i | 10.77646914 | -73.39924382 | 2,76600692550577-1,00908333692602i | 9.379711818 | -0,611277321029247-10,1630696651038i | 20.15618096 | 86.55798211
3.1 | 1258.925412 | 7910.06165 | -15,1600728412752-45,677480529045i | 33.64787314 | -108.3606858 | 0.1 | 1.259 | 7.910 | 0.014 | 45,2392872702479-191,035456432884i | 45.85924542 | 0,642715301896824-2,71404388669508i | 8.909303134 | -76.67715919 | 2,76239166589908-0,862184088736169i | 9.229417273 | -0,56457406173457-8,05139112037354i | 18.13872041 | 85.98891068
3.2 | 1584.893192 | 9958.17762 | -14,3285140080478-34,2927257077229i | 31.40287179 | -112.6766133 | 0.2 | 1.585 | 9.958 | 0.014 | 29,1146116456367-154,777999002592i | 43.94519789 | 0,413631768813047-2,19893358977298i | 6.995255608 | -79.34682734 | 2,75668118389053-0,760941895657524i | 9.12664297 | -0,533009780080572-6,37650859381681i | 16.12189858 | 85.22177708
3.3 | 1995.262315 | 12536.60286 | -13,182501099667-25,0610157467849i | 29.04083842 | -117.7450987 | 0.3 | 1.995 | 12.537 | 0.014 | 18,604717952676-124,514897876852i | 42.00031878 | 0,264317535425087-1,76898521193556i | 5.050376498 | -81.50187162 | 2,74767888374506-0,69971247254557i | 9.05220223 | -0,511521305848931-5,04554958874206i | 14.10257873 | 84.21109307
3.4 | 2511.886432 | 15782.64792 | -11,6994570090067-17,6671525500571i | 26.52251732 | -123.5131314 | 0.4 | 2.512 | 15.783 | 0.014 | 11,8341570389117-99,7092740395159i | 40.03546116 | 0,168128064629363-1,41657130412765i | 3.085518873 | -83.23142079 | 2,73353101725272-0,674738020325438i | 8.991342357 | -0,496231237861881-3,98568399547223i | 12.07686123 | 82.90300029
3.5 | 3162.27766 | 19869.17653 | -9,92908174576995-11,9099500314801i | 23.80995112 | -129.8172759 | 0.5 | 3.162 | 19.869 | 0.014 | 7,50532293281784-79,6099973859371i | 38.05778171 | 0,106628246943483-1,13102054853897i | 1.107839427 | -84.6142937 | 2,71140418523281-0,683719070032046i | 8.931614565 | -0,484188042607602-3,13955761473222i | 10.03945399 | 81.23281691
3.6 | 3981.071706 | 25013.81125 | -8,00843575946841-7,63042186104285i | 20.87633722 | -136.3846526 | 0.6 | 3.981 | 25.014 | 0.014 | 4,75098479689056-63,4427305971501i | 36.07192429 | 0,0674973195267142-0,901331922081866i | -0.8780180007 | -85.71733071 | 2,6770599906436-0,725267872237922i | 8.860767457 | -0,473012711727778-2,46187326421016i | 7.982749456 | 79.12399938
3.7 | 5011.872336 | 31490.52262 | -6,12932994272932-4,63888763796303i | 17.71499026 | -142.8803114 | 0.7 | 5.012 | 31.491 | 0.014 | 3,00385076208466-50,4982791072426i | 34.0808714 | 0,0426757574201648-0,717429885837891i | -2.869070886 | -86.59581653 | 2,62437523085858-0,798078650954301i | 8.764646533 | -0,460568274712192-1,916863833181i | 5.895575647 | 76.48954417
3.8 | 6309.573445 | 39644.21916 | -4,46783041826372-2,68594758740209i | 14.34182707 | -148.9867707 | 0.8 | 6.310 | 39.644 | 0.014 | 1,89777109160988-40,1644711595998i | 32.08652615 | 0,0269616652620714-0,570617305543749i | -4.863416139 | -87.29478665 | 2,54499473827154-0,899603966746738i | 8.625061852 | -0,444712295334482-1,47647286119538i | 3.761645712 | 73.23774603
3.9 | 7943.282347 | 49909.11493 | -3,12518150067988-1,4923685837534i | 10.78961271 | -154.4741151 | 0.9 | 7.943 | 49.909 | 0.014 | 1,19839778162275-31,9300223579066i | 30.09009784 | 0,0170256570888706-0,453630355331233i | -6.859844443 | -87.85058336 | 2,42857173569567-1,02408288402905i | 8.417789458 | -0,423207052983054-1,11910954342508i | 1.557945014 | 69.28518156
4 | 10000 | 62831.85307 | -2,11692464385793-0,802982816895957i | 7.097914248 | -159.2274756 | 1 | 10.000 | 62.832 | 0.014 | 0,756530613012441-25,3760915616719i | 28.09235294 | 0,0107480429218932-0,360518552195397i | -8.857589343 | -88.29236209 | 2,26439765139609-1,16013839130596i | 8.111336384 | -0,393913570030482-0,828826580101068i | -0.7462529593 | 64.57982127
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

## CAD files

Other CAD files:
pcb/symbols/ind_pfcinductor_v1.psm

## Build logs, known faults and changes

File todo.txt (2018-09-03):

!!! PFC не отключается кнопкой питания.

!!! Проверить пороги включения/отключения PFC. Ваня говорит что использовал дополнительный монитор.

В СП надо добавить хомут (532142B) для крепления индуктивности. ПОдумать над заменой индуктивности на стандартную. ---> после пайки опытной платы внести хомут для крепления позю37 в СП и указать его поз. в ТТ

Для крепления радиатора надо указать клей. Подумать над заменой, для крепления на плату.

Подумать над установкой выводных элементов горизонтально.

*** Замечания от ЦМПП: ***

Спецификация Плата BP2_02v7
На Сб  указать габаритные размеры платы, пю 8, 9 ТТ откорректировать в соответствии с внесенными в СП деталями и материалами. 
Вариант установки поз. 94 идентичен варианту установки поз.95. 
указать  способ крепления на радиатор элементов D2 D8 Q2, внести крепеж в СП
В Сп  поле документация кол-во 1, корпус поз.37 указать кол-во выводов 2

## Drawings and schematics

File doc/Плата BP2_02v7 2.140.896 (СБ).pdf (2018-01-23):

4

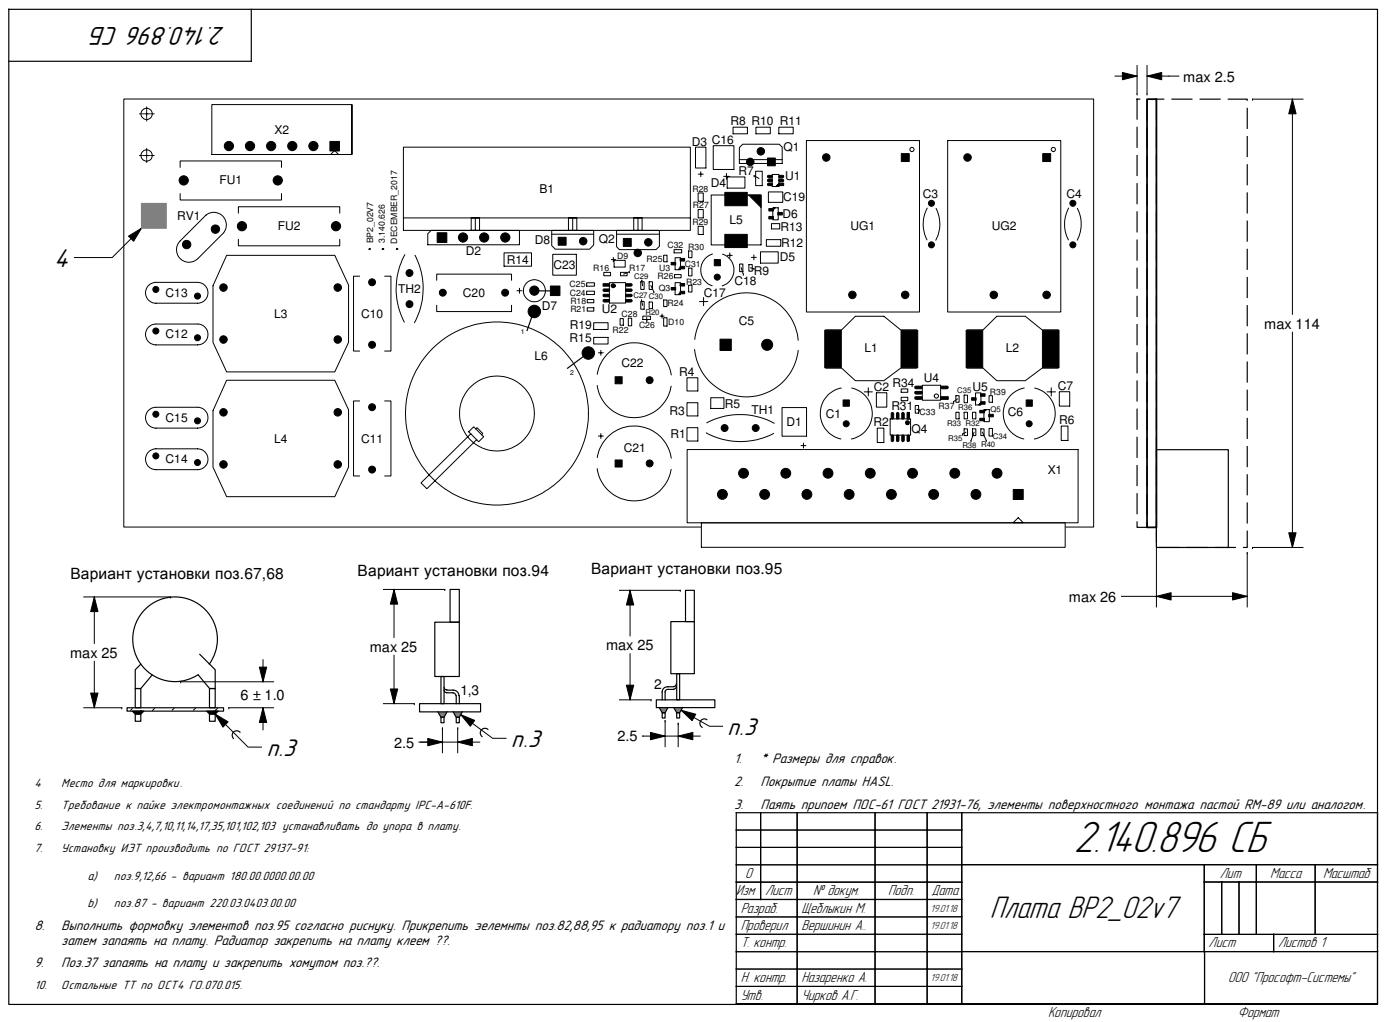
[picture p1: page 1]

1. * Размеры для справок.
2. Покрытие платы HASL.
3. Паять припоем ПОС-61 ГОСТ 21931-76, элементы поверхностного монтажа пастой RM-89 или аналогом.

4 Место для маркировки.
5. Требование к пайке электромонтажных соединений по стандарту IPC-A-610F.
6. Элементы поз.3,4,7,10,11,14,17,35,101,102,103 устанавливать до упора в плату.
7. Установку ИЭТ производить по ГОСТ 29137-91:

0 | | | | | Ïëàòà BP2_02v7 | Ëèò | Ìàññà | Ìàñøòàá
Èçì | Ëèñò | ¹ äîêóì. | Ïîäï. | Äàòà
Ðàçðàá. | | Ùåáëûêèí Ì. | | 19.01.18
Ïðîâåðèë | | Âåðøèíèí À.. | | 19.01.18
Ò. êîíòð. | | | | | Ëèñò | Ëèñòîâ 1

8. Выполнить формовку элементов поз.95 согласно риснуку. Прикрепить эелемнты поз.82,88,95 к радиатору поз.1 и
затем запаять на плату. Радиатор закрепить на плату клеем ??.
9. Поз.37 запаять на плату и закрепить хомутом поз.??.
10. Остальные ТТ по ОСТ4 ГО.070.015.

Í. êîíòð. | Íàçàðåíêî À. | 19.01.18
Óòâ. | ×èðêîâ À.Ã.

ÎÎÎ "Ïðîñîôò-Ñèñòåìû"

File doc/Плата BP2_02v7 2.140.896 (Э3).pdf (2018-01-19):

## PROSOFT-SYSTEMS

## MARKING STICKER

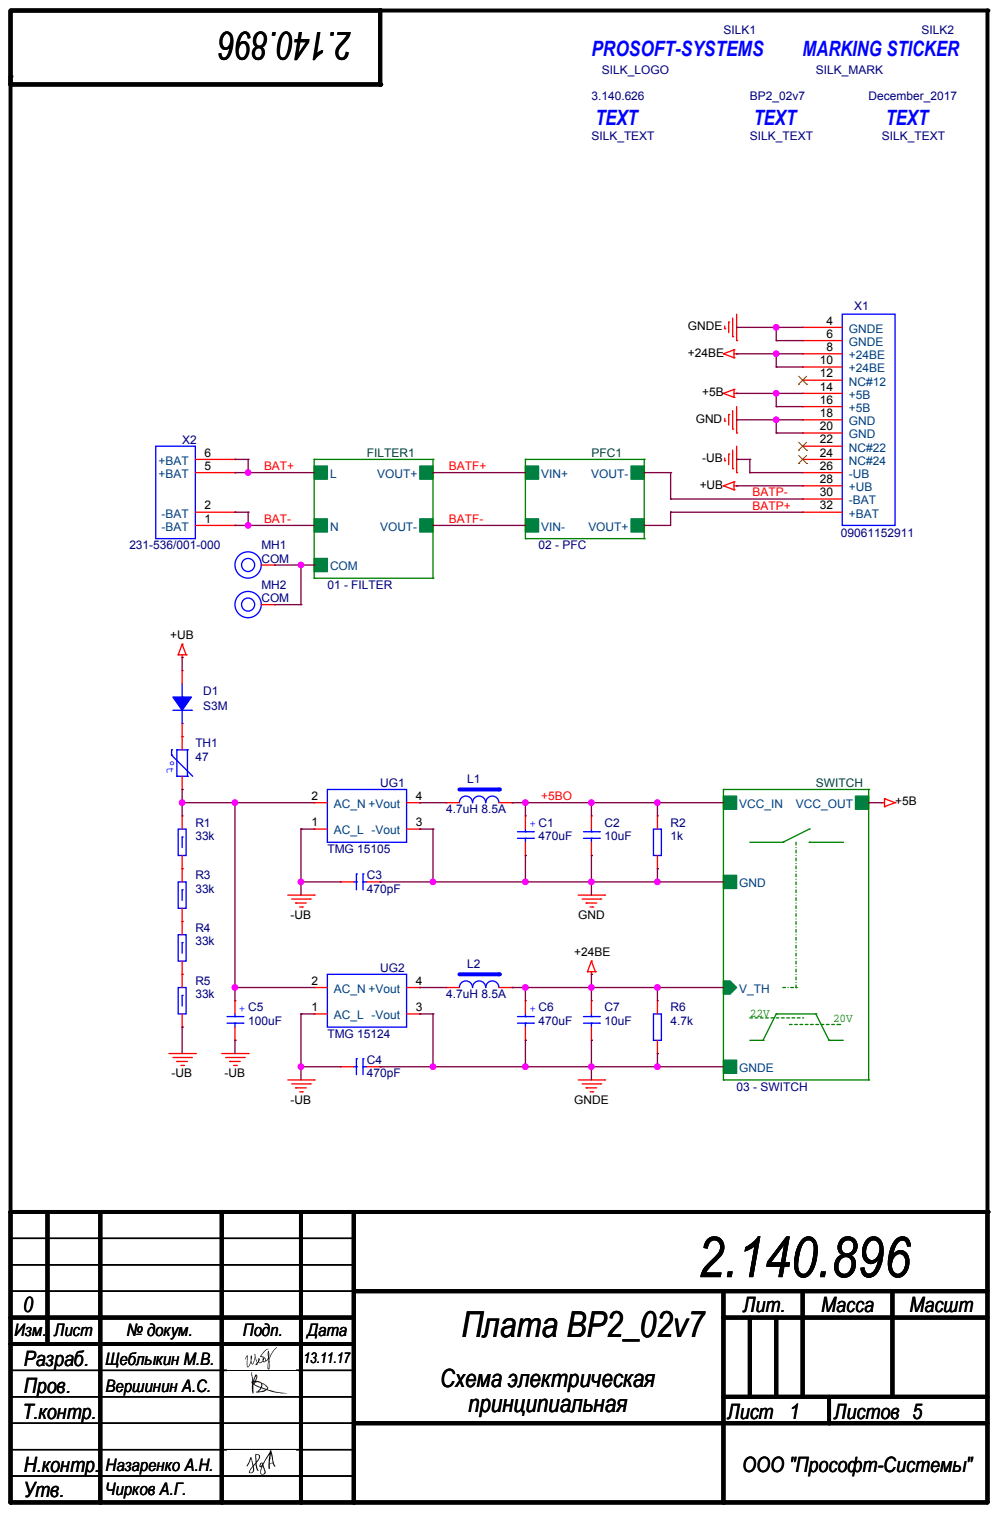
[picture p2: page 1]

0 | | | | | Плата BP2_02v7 Плата BP2_02v7 Плата BP2_02v7 Схема электрическая Схема электрическая Схема электрическая | Лит. | Масса Масса Масса | Масшт Масшт Масшт
Изм. Изм. Изм. | Лист Лист Лист | № докум. № докум. № докум. | Подп. Подп. Подп. | Дата Дата Дата
Разраб. Разраб. Разраб. | | Щеблыкин М.В. Щеблыкин М.В. Щеблыкин М.В. | | 13.11.17 13.11.17 13.11.17
Пров. Пров. Пров. | | Вершинин А.С. Вершинин А.С. Вершинин А.С.
принципиальная Т.контр. принципиальная Т.контр. принципиальная Т.контр. | Лист Лист Лист 1 5 1 5 1 5 | Листов Листов Листов

Н.контр. Н.контр. Н.контр. | Назаренко А.Н. Назаренко А.Н. Назаренко А.Н.
Утв. Утв. Утв. | Чирков А.Г. Чирков А.Г. Чирков А.Г.

ООО "Прософт-Системы" ООО "Прософт-Системы" ООО "Прософт-Системы"

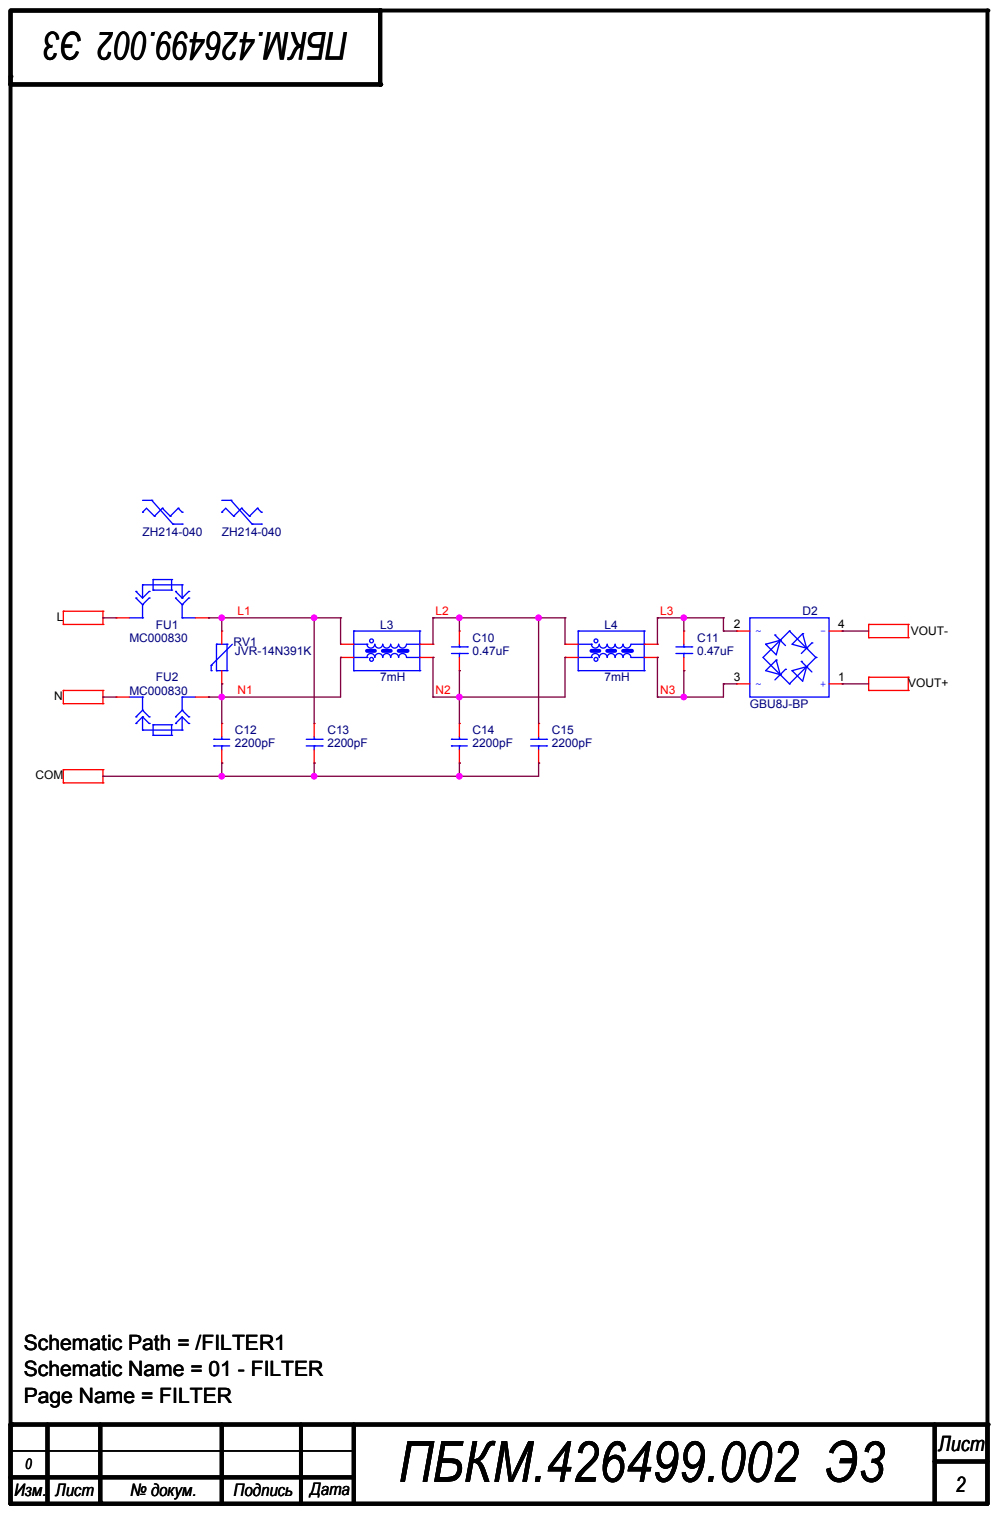
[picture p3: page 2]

Лист ПБКМ.426499.002 Э3 Лист ПБКМ.426499.002 Э3 Лист ПБКМ.426499.002 Э3 2 2 2

Изм. | Лист | № докум. | Подпись | Дата

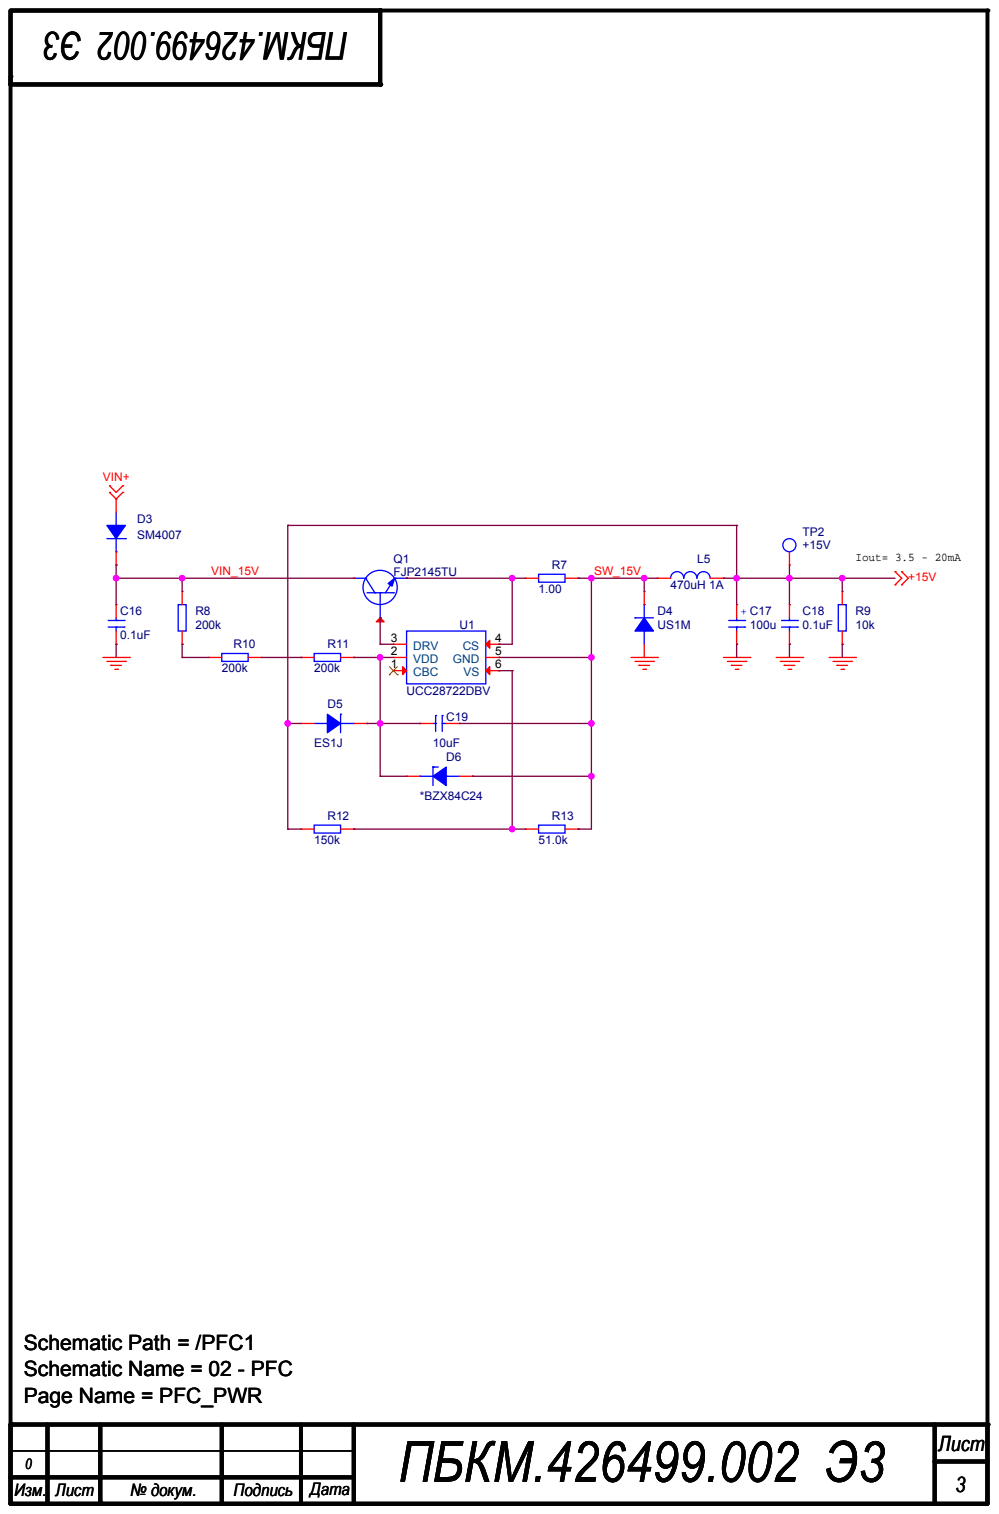
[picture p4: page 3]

## радиатор 3.181.006

### Z:\Текущие версии железа\AVAX.PWR.PFCS6\PFCINDUCTOR\ - тут доки на индуктор

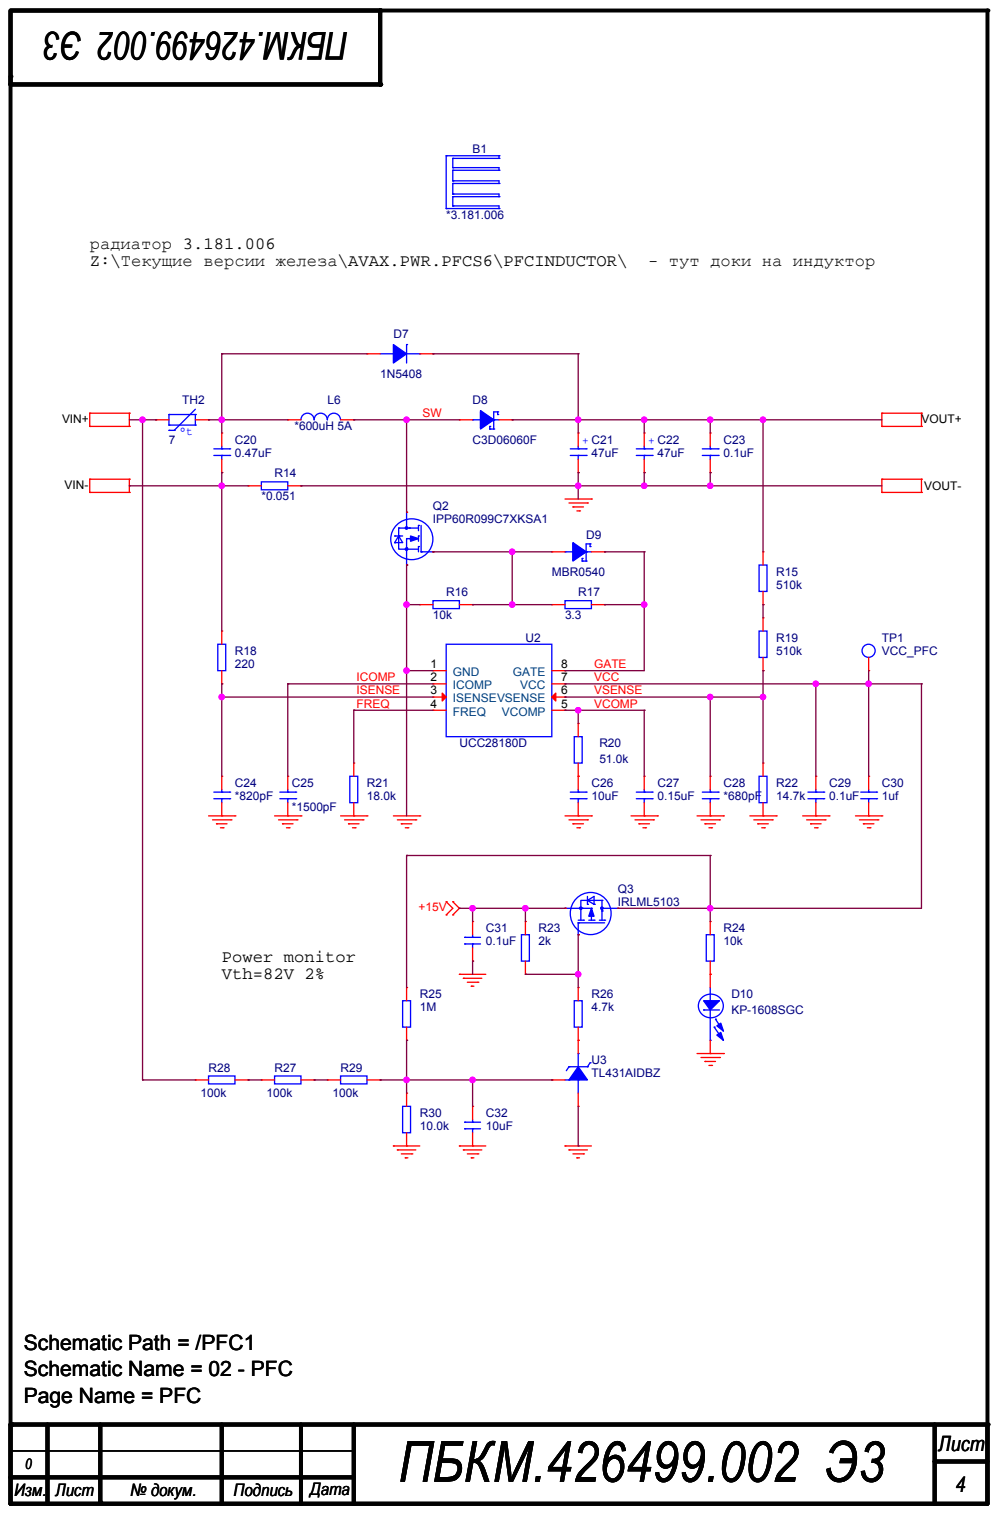
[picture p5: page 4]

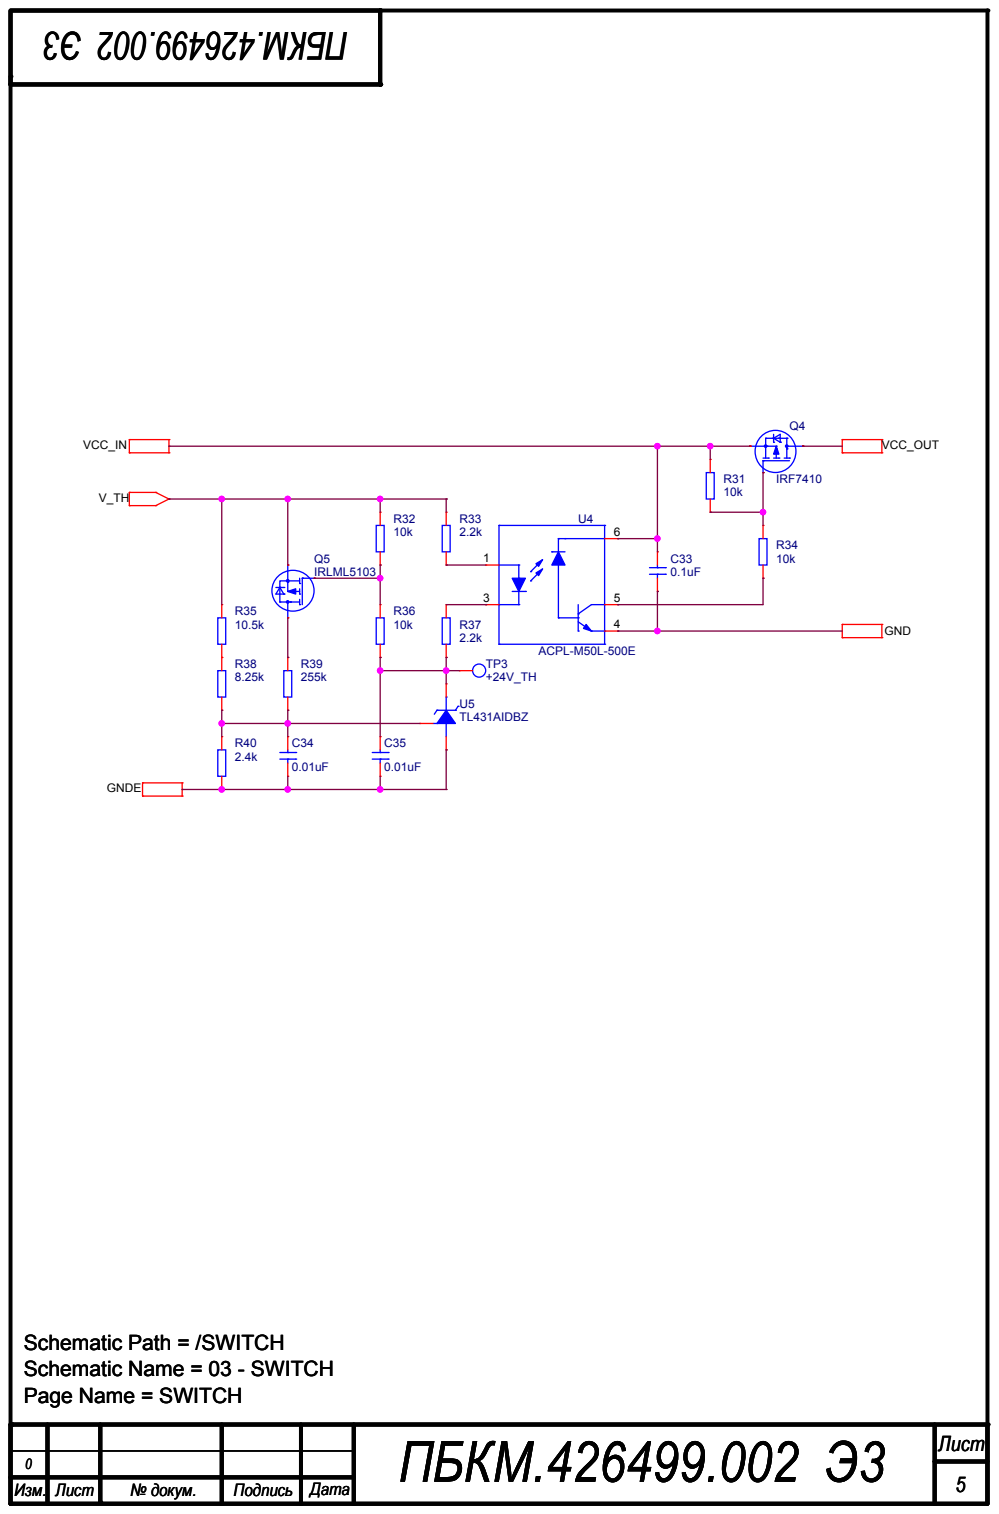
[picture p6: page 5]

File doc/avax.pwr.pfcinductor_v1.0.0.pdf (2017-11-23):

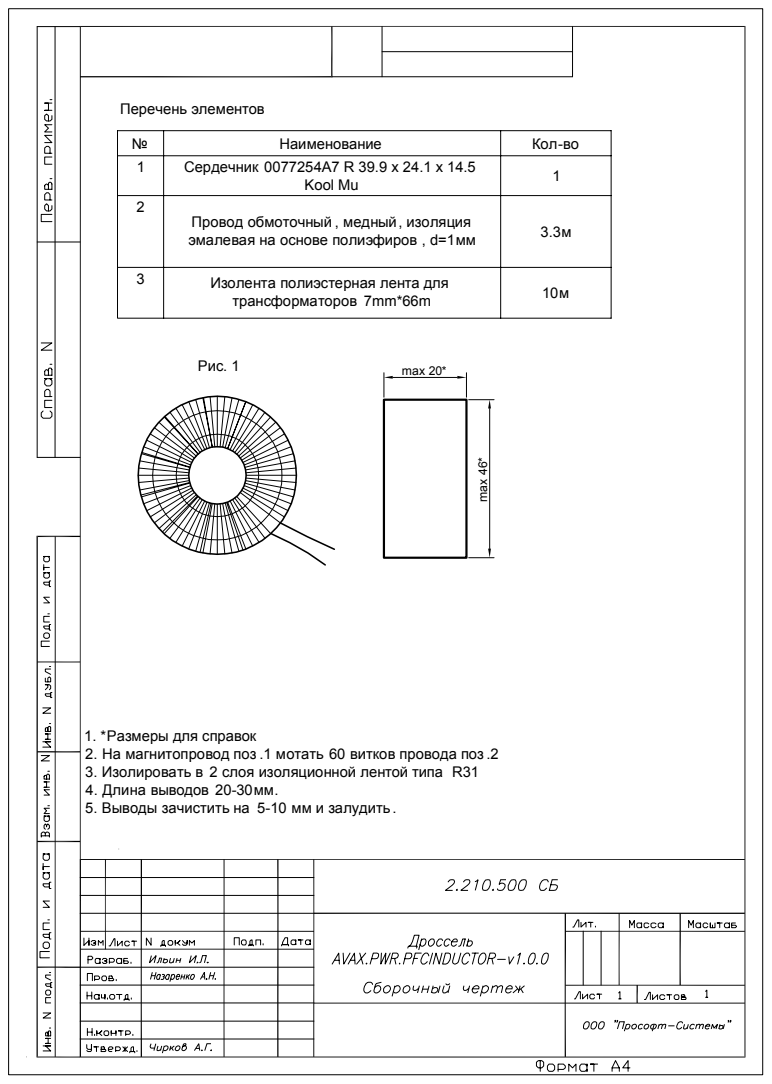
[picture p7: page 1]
Перечень элементов; Рис. 1; max 20*; max 46*

№ | Наименование | Кол-во
1 | Сердечник 0077254A7 R 39.9 x 24.1 x 14.5 Kool Mu | 1

2 | Провод обмоточный , медный, изоляция эмалевая на основе полиэфиров , d=1мм | 3.3м

3 | Изолента полиэстерная лента для трансформаторов 7mm*66m | 10м

1. *Размеры для справок
2. На магнитопровод поз .1 мотать 60 витков провода поз .2
3. Изолировать в 2 слоя изоляционной лентой типа R31
4. Длина выводов 20-30мм.
5. Выводы зачистить на 5-10 мм и залудить .

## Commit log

2014-11-28 Добавлены файлы для платы управления.
    [BP2_02V4.DSN, BP2_02V4.brd, BP2_02_ctrl.DSN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]
2014-11-28 Изменен тип диэлектрика для конденсаторов на X7R.
2015-02-13 Перерисована схема БП2.
    [BP2_02V4.DSN]
2015-02-16 Доделана схема (несколько элементов надо обновить). Начата расстановка площадок.
    [BP2_02V4.DSN, BP2_02V4.brd]
2015-02-25 Закончена предварительная разводка.
    [BP2_02V4.DSN, BP2_02V4.brd]
2015-03-16 Добавлены файлы заказа и документация.
    [BP2_02V4.DSN, BP2_02V4.brd, art_param.txt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]
2015-04-29 Изменен общий документ, убран Э3 из него.
2015-06-03 Добавлены обнаруженные замечания по спаянной плате.
2016-07-14 В симуляторе исправлен номинал резистора (соответствующего R7 на схеме) с 5.1 кОм на 2.2 кОм. В файл описания добавлены измеренные на одной плате пороги: 22.5 В включение, 21.9 В отключение.
2016-12-02 Начата работа над платой 02v5.
2016-12-02 Добавлена возможность установки AC/DC TMG 15W. Схема управления сделана на WD вместо компаратора.
    [BP2_02V4.DSN, BP2_02V5.DSN, BP2_02V5.brd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]
2016-12-05 Доделана схема и разводка.
    [BP2_02V5.DSN, BP2_02V5.brd]
2016-12-07 НА схеме добавлен децимальный номер. Сделано вариантное исполнение. НА ПП заменены переходные отверстия на V800H400. Так же приведен в порядок слой сборки.
    [BP2_02V5.DSN, BP2_02V5.brd, Плата БП2 ПБКМ.426499.002 02v4 (СБ).dwg]
2016-12-07 Добавлена документация и гербера.
    [art_param.txt, nc_param.txt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]
2016-12-08 В СП исправлено название.
2017-02-02 На СБ: В 6 пункте ТТ исправлена поз.51 на 59. Добавлены поз.39 и 41 в пункт 5 ТТ. Добавлена ширина ПП.
2017-02-02 Обновлен общий файл СП/СБ.
2017-02-09 На СБ исправлен номер ревизии на 0.
2017-02-20 Измерены реальные пороги 21.9 / 19.7 В. Источники TMG не заработали. Необходимо подавать "-" на L, "+" на N.
2017-04-05 У источников TMG "-" подан на L, "+" на N. На плате место для маркировки изменено на 6х6мм. В СБ добавлен пункт ТТ о месте для маркировки.
    [BP2_02V5.DSN, BP2_02V5.brd, BP2_02V6.DSN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]
2017-04-05 Удалена старая документация.
2017-04-05 На СБ исправлено название платы и ее артикул.
2017-04-07 Планарные элементы сдвинуты так, чтобы расстояние от них до края платы по длинной стороне было не менее 5мм.
    [BP2_02V6.brd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]
2017-04-07 Исправлен сборочный чертеж.
    [BP2_02V6.brd]
2017-04-07 Добавлен файл заказа.
    [BP2_02v6 07.04.17.xls]
2017-11-15 Сделана предварительная схема по плате AVAX_PWR_PFCS6_V100.
    [BP2_02V6.DSN, BP2_02V6.brd, BP2_02V7.brd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]
2017-11-16 Исправлена схема согласно AVAX_PWR_PFCS6_V110 и рассчетам для микросхемы UCC28180D (sluc506a.xls).
    [BP2_02V7.brd, BP2_02v7.DSN, sluc506a.xls]
2017-11-23 Переделана схема управления 24В -> 5В. Скорректированы номиналы элементов в обвязке PFC.
    [BP2_02V7.brd, BP2_02v5_Hyst.dsn, BP2_02v7.DSN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]
2017-11-23 Частично раскиданы элементы.
    [BP2_02V7.brd, BP2_02v7.DSN]
2017-11-23 Разъем DIN обновлен из ЦБ. Ведется разводка цепей 24В и 5В.
    [BP2_02V7.brd, BP2_02v7.DSN]
2017-11-24 Сделана разводка цепей 24В и 5В.
    [BP2_02V7.brd, BP2_02v7.DSN]
2017-11-24 Разведен входной фильтр.
    [BP2_02V7.brd, BP2_02v7.DSN]
2017-11-24 Проводники по 24В и 5В по возможности заменены на 2.5мм.
    [BP2_02V7.brd]
2017-11-28 Перетащил планарные элементы на слой BOTTOM.
    [BP2_02v7.DSN]
2017-11-28 Разведен источник 15В и ключ для питания PFC.
    [BP2_02v7.DSN]
2017-11-29 Начал прикидывать разводку PFC.
2017-11-30 Закончена предварительная разводка. Планарные элементы, за исключением дросселей, расположены на стороне BOTTOM.
2017-11-30 Попытка разместить все элементы на TOP.
2017-12-01 Осталось поставить ключ для 15В.
2017-12-04 Сделана часть разводки с полигонами.
2017-12-05 Доделана разводка.
2017-12-06 Закончена разводка. У индуктивности вырезы в плате перенесены на слой NCROUTE_PATH. Добавлены децимальные номера на ПП и плату сборе.
    [BP2_02v7.DSN, ind_pfcinductor_v1.psm]
2017-12-06 Добавлены файлы для заказа ПП.
    [BP2_02v6 07.04.17.xls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]
2018-01-19 Добавлена документация. На плате исправлен слой сборки для индуктивности L6.
    [BP2_02v7 06.12.17.xls, ind_pfcinductor_v1.psm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]
2018-01-23 Добавлен СБ.
2018-05-14 Добавлены замечания от ЦМПП.
2018-09-03 PFC стоит до кнопки + необходимо проверить пороги включения/выключения.
